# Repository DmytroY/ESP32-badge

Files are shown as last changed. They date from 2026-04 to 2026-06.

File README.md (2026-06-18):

# Electronic Conference Badge (ESP32)
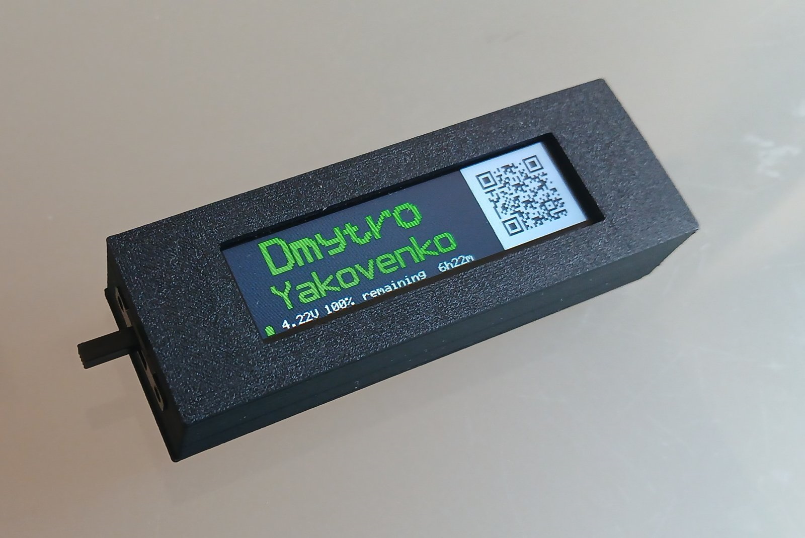
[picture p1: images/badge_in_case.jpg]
bage front view


A low-power embedded system featuring a custom display driver, web-based asynchronous configuration portal.
Is a result of full-stack embedded development, from low-level SPI driver authorship to UI/UX and power profiling.

## 1.Technical Overview
The system utilizes an ESP32 Super Mini to drive a 76x284 ST7789 LCD. With integrated WiFi it hosts a local web server to customize text, colors, and QR codes. Then transit into a power-efficiency monitoring state to maximize battery life while maintaining the display.

### 1.1. Custom Driver Development (ST7789)
Existing libraries failed to support the non-standard 76x284 resolution and integrated backlight control efficiently. So I developed a dedicated driver (lib/ST7789_76x284/) supporting drawing primitives, text rendering, and QR code generation. As important feature for this project the driver has integrated LEDC-based PWM for fine-grained backlight brightness control, allowing users to balance visibility against power consumption. 

[Driver API documentation link.](https://github.com/DmytroY/ESP32-badge/tree/main/lib/ST7789_76x284)

### 1.2. High-Frequency Hardware Integration & EMI Mitigation
During prototyping, long trace lengths led to significant RF interference between the WiFi antenna and the SPI bus/PWM signals. So I optimized physical pinout which allows reduce betwing boards connection lengths to <5mm for critical high-speed lines (SCLK, MOSI) and move the antenna to the edge of the device. This effectively eliminated signal crosstalk and ensured stable work of SPI and WiFi.

**NB !** 
- SCLK: 7
- MOSI: 8
- CS: 20
- DC: 10
- RST: 9
- Backlight (BL): 21
- Battery ADC: 0

 this ESP32 to LCD pinout is recomended to keep connections as short as possible and WiFi antenna on the edge of the device which prevents EMI.

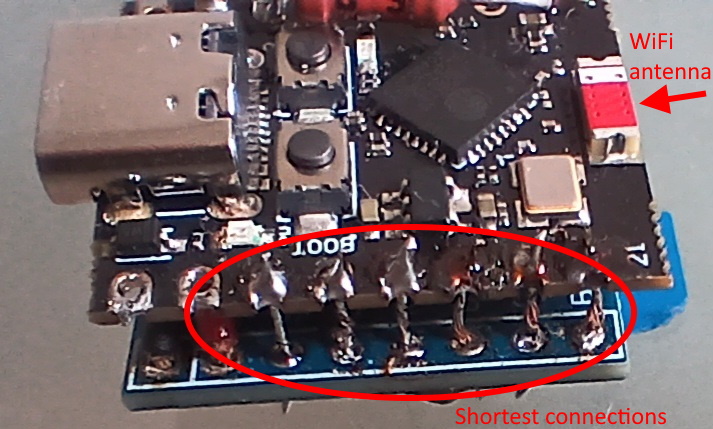
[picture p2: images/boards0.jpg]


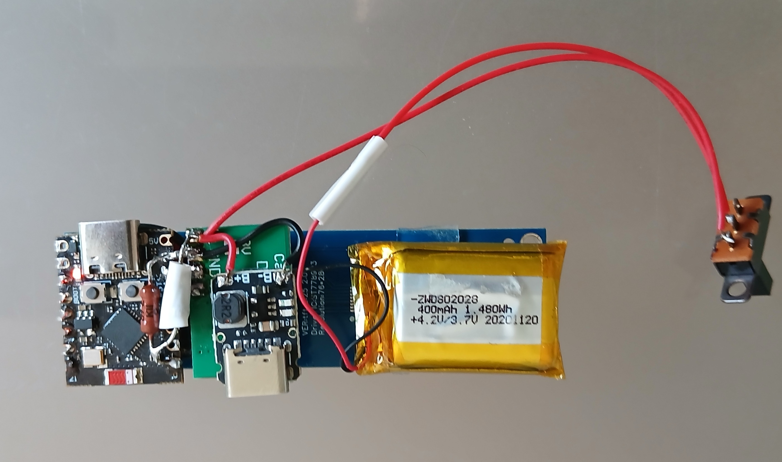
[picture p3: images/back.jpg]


### 1.3. Power Management & Battery Analytics
To achieve maximum operational uptime without losing the display state, the system employs next power strategy:

#### Optimized Light Sleep.
Since the display requires a PWM signal for the backlight, Deep Sleep was bypassed in favor of Light Sleep. This maintains the oscillator and pin registers while powering down the majority of the SoC.

#### Battery measurement Logic.
* ESP32-specific ADC non-linearity mitigated by implementing ADC characterization.
``` esp_adc_cal_characterize(ADC_UNIT_1, ADC_ATTEN_DB_11, ADC_WIDTH_BIT_12, 1100, &adc_chars); ```

* Digital Signal Processing using an Exponential Moving Average (EMA) filter to stabilize voltage readings:
``` bat_v = (bat_v_raw * 0.1f) + (bat_v * 0.9f);```

* to calculate remaining battery capacity accurately I use approximated voltage zones of non-linear voltage/capacity function of Li-Ion battery then provide real-time runtime estimates.

#### Consumption and lifetime
There are two modes of functioning.
* SETUP mode. System starts with running WiFi and server. After user input data and chose brightness sytem state transfers to
* DISPLAY mode. ESP32 shouts down server and WiFi, going to sleep mode. Only PWM for display backlight works and battery comsumption mostly depends on chosen screen brightness.

| Mode | Brightness| Current (mA)|
|------|-----------|-------------|
| Setup  | 50%     |     170     |
| Display| min     |     24      |
| Display| 50%     |     60      |
| Display| max     |     110     |

### 1.4. Software Architecture
The badge implements a "headless" configuration mode to keep the firmware footprint small and the UI responsive.

* Filesystem: HTML, CSS, and JS assets are decoupled from the binary and stored in Flash memory via **LittleFS**.

* Asynchronous Communication: The configuration portal uses **AJAX** (XMLHttpRequest) to submit user data (Title, Subtitle, Colors) without page refreshes, ensuring a seamless user experience.

### 1.5. Helper Utilities
The helper.cpp file provides procedures for
- File Serving: Logic for handling LittleFS file requests for the web server.
- Power Management: Routines for deep sleep and wake cycles.
 - Battery Diagnostics: Procedures for measuring ADC voltage and rendering battery status/remaining time indicators on the screen.

## 2. Hardware Configuration
The circuit is powered by a Li-ion battery, so it was necessary to address the issues of battery charging, charge level monitoring, and converting the Li-ion battery voltage to the 3.3 V supply voltage for the microcontroller and display. The following components were used:
- TP4056 - Li-ion battery charge controller with USB Type-C input 
- 350 or 400 mAh Li-ion battery
- DD0603SA DC/DC converter from 0.9-6V to 3.3V
- Power switch
- ESP32-C3_SuperMini development board with onboard WiFi
- 2.25-inch TFT LCD 76x284 resolution module with SPI interface and ST7789 controller 
- 7.5k / 6.2k divider connects the battery to PIN_0 (ADC) and shifts the voltage to the optimal ADC range.

<img src="images/badge_schematic.jpg" alt="bage schematic" width="500">

## 3. Software Installation notes
I have used PlatformIO IDE extension in VS Code. After cloning repository do not forget that Filesystem Image and main code should be uploaded separatelly:

- Upload to ESP32 filesystem: Open the PlatformIO sidebar, go to Project Tasks > Platform > Build Filesystem Image, click Upload Filesystem Image.

 - Upload Code: click the standard Upload arrow icon.

## 4. Usage
Watch Youtube video:

[![Watch the video](https://img.youtube.com/vi/PrKOngyS30c/2.jpg)](https://youtu.be/PrKOngyS30c)

- On power on the badge generates a unique SSID based on its MAC address.

<img src="images/badge_connect_WiFi.jpg" alt="WiFi connection screen" width="300">

- You can scan the QR code on the display or manually connect to the WiFi using password on screen.

- Visit 192.168.4.1 in your browser.

<img src="images/server0.jpg" alt="server initial page" width="300">

- Input Title (Name), Subtitle (Position or Surname), and string for generating QR Code (Link), choose colors and brightness.

<img src="images/server1.jpg" alt="server page with user input" width="300">

- Use the Test button to preview your design. Once satisfied, press Finish.

<img src="images/displ01.jpg" alt="display 3 fields" width="300">

<img src="images/displ02.jpg" alt="display 1 field" width="300">

**Remarks:** In case of Subtitle is not used Title field font and position will be automaticaly adjusten for beter visibility:

<img src="images/Title_only.jpg" alt="display 1 field" width="300">

- The badge will keep screen on, but enters sleep mode, waking briefly every 60 seconds to monitor battery and dispaly remaining time.

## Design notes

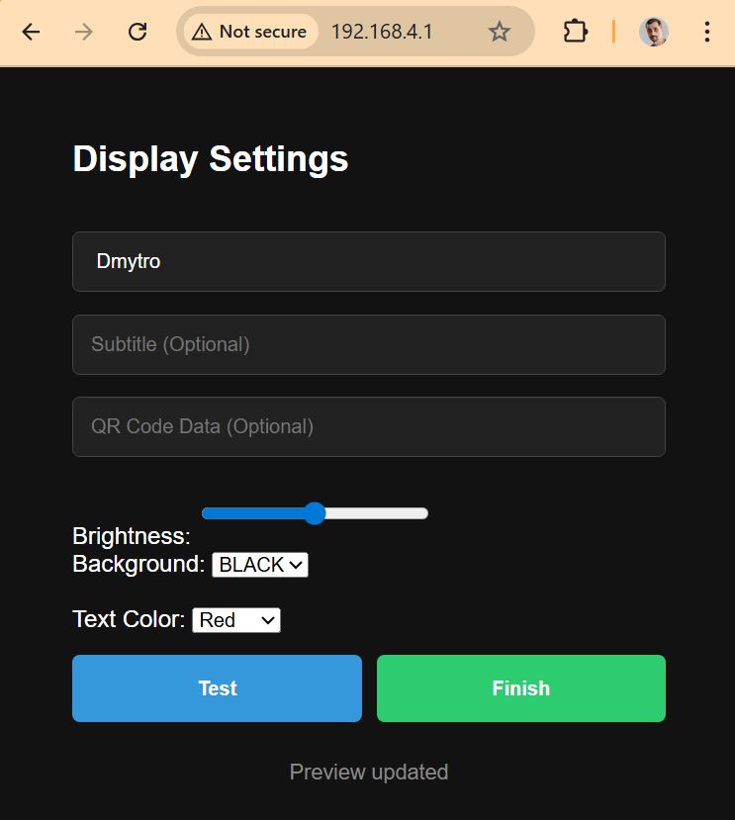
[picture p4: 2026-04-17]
images/server2.jpg

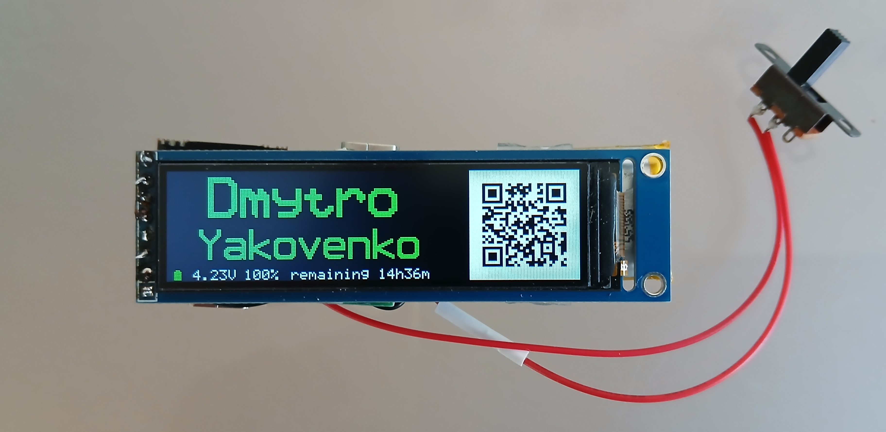
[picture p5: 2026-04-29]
images/displ02.jpg

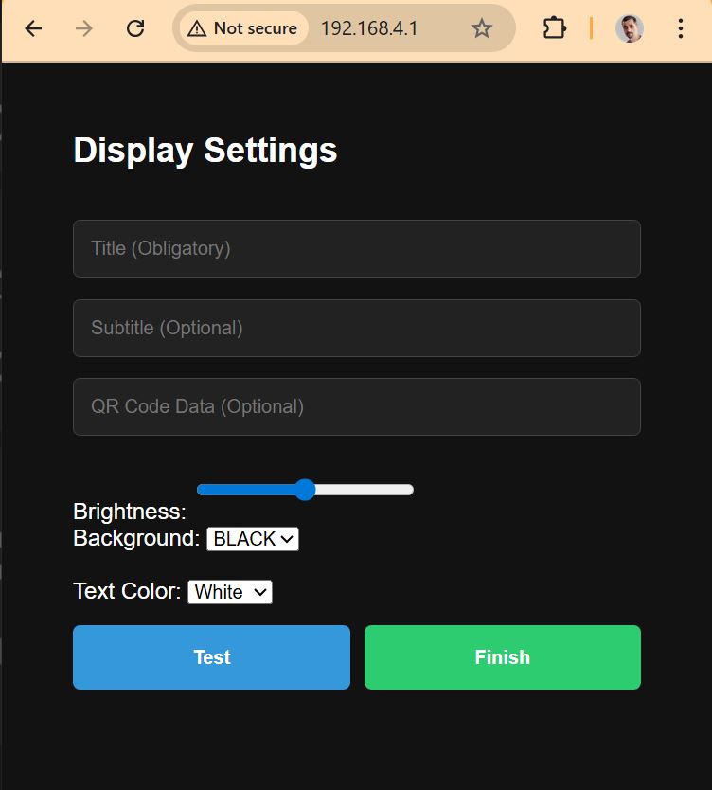
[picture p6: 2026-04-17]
images/server0.jpg

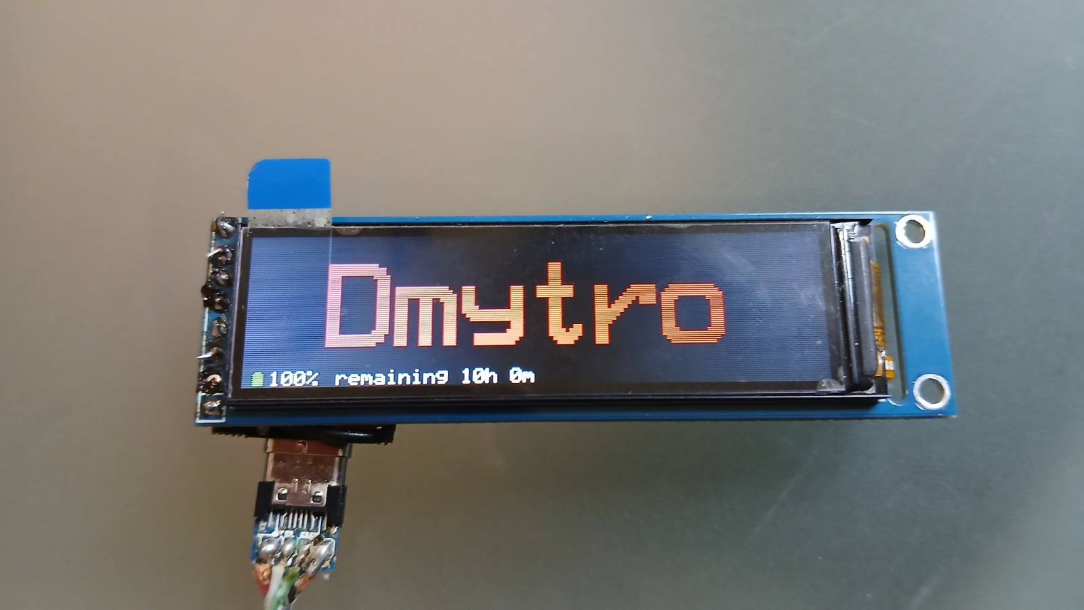
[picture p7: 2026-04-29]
images/Title_only.jpg

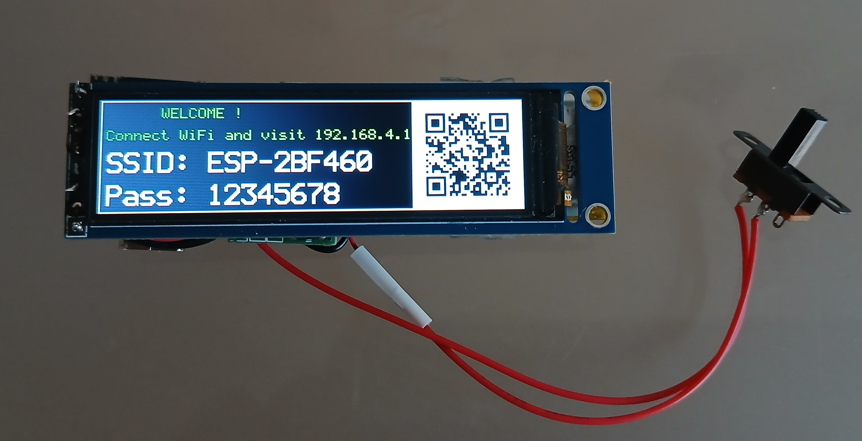
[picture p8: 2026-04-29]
images/displ00.jpg

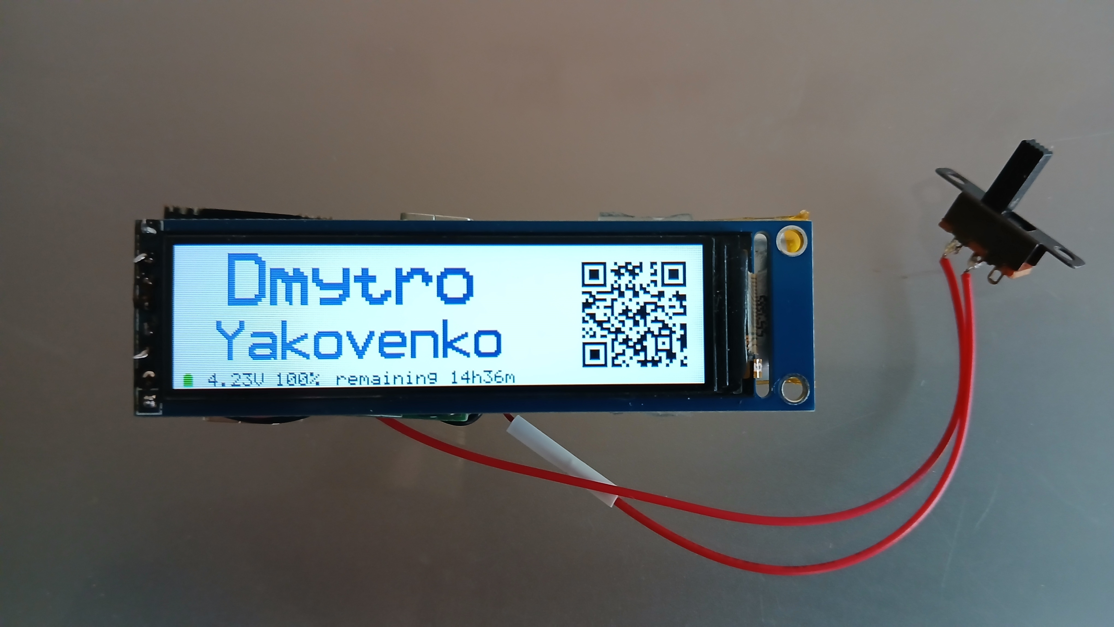
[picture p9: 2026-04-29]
images/displ01.jpg

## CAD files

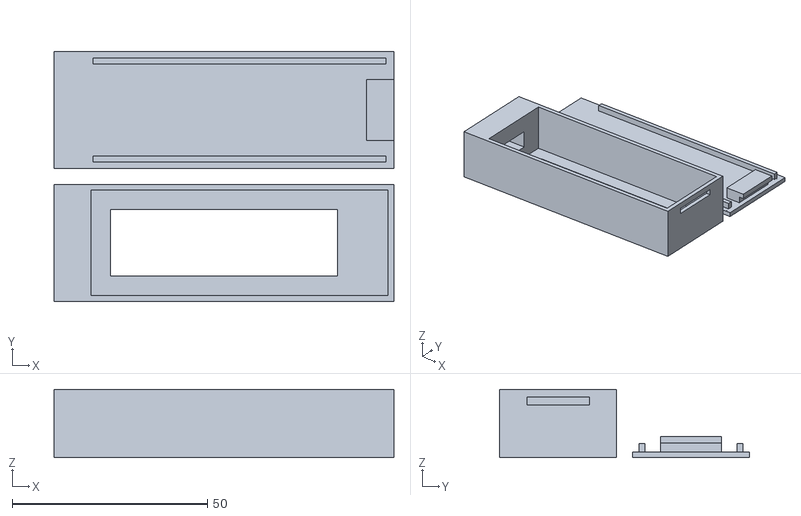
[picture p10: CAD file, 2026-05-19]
Badge case walls 1_5 mm.stl
87.0 x 64.0 x 17.5

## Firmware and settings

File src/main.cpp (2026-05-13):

#include <Arduino.h>
#include <WiFi.h>
#include "esp_wifi.h"
#include <ST7789_76x284.h>
#include "helper.h"


// --- WiFi settings ------
uint8_t mac[6];
char ssid[20]; // wil be determined based on WiFi MAC to be unique
#define PASS "12345678"

// ── Pin definitions ─────────────────────────────────────────────────
#define PIN_SCLK  7
#define PIN_MOSI  8
#define PIN_CS    20
#define PIN_DC    10
#define PIN_RST   9
#define PIN_BL    21
#define PIN_BAT   0

// ── Display geometry ────────────────────────────────────────────────
// landscape
#define TFT_W      284
#define TFT_H      76
#define X_OFFSET   18
#define Y_OFFSET   82

ST7789_76x284 tft(TFT_W, TFT_H, X_OFFSET, Y_OFFSET);
WebServer server(80);

unsigned brightness = 50;  // initial brightness 50%
const unsigned long TIMEOUT_MS = 300000; // 5 minutes timeout user activity 

String userTitle = "";
String userSubtitle = "";
String userQR = "";
String currentAction = "";;
bool newMessageReady = false;

uint16_t userTextColor = WHITE;
uint16_t userBgColor = BLACK;

// ── Setup ───────────────────────────────────────────────────────────
void setup() {

    esp_adc_cal_characterize(ADC_UNIT_1, ADC_ATTEN_DB_11, ADC_WIDTH_BIT_12, 1100, &adc_chars); // ADC calibration
    analogReadResolution(12);    // set resolution for ADC

    LittleFS.begin();

    WiFi.macAddress(mac);
    snprintf(ssid, sizeof(ssid), "ESP-%02X%02X%02X", mac[3], mac[4], mac[5]);
    WiFi.mode(WIFI_AP);
    WiFi.setTxPower(WIFI_POWER_2dBm); // decreased WiFi power
    WiFi.softAP(ssid, PASS, 1);

    serveFile(server, "/", "/index.html", "text/html");
    serveFile(server, "/style.css", "/style.css", "text/css");
    serveFile(server, "/script.js", "/script.js", "application/javascript");

    server.on("/msg", []() {
        userTitle = server.arg("title");
        userSubtitle = server.arg("subtitle");
        userQR = server.arg("qr");
        currentAction = server.arg("action"); // "test" or "finish"

        userTextColor = (uint16_t)strtol(server.arg("textColor").c_str(), NULL, 0);
        userBgColor = (uint16_t)strtol(server.arg("bgColor").c_str(), NULL, 0);
        brightness = server.arg("bright").toInt();

        // Safety Fallback: if colors match, force text to contrast
        if (userTextColor == userBgColor) {
            userTextColor = (userBgColor == 0x0000) ? 0xFFFF : 0x0000;
        }
        
        newMessageReady = true;
        server.send(200, "text/plain", "OK");
    });

    server.begin();

    tft.begin(PIN_SCLK, PIN_MOSI, PIN_CS, PIN_DC, PIN_RST, PIN_BL);
    tft.fillScreen(BLACK);
    // tft.drawRect(0, 0, TFT_W, TFT_H, WHITE);
    
    tft.drawText(5,   5, "Connect WiFi, visit 192.168.4.1", GREEN, BLACK, 1);

    // WIFi ON simbol
    tft.drawChar(0, 20, (char)0x86, WHITE, BLACK, 3);

    static char buf[32];
    snprintf(buf, sizeof(buf), "SSID:%s", ssid);
    tft.drawText(20,   20, buf, WHITE, BLACK, 2);
    snprintf(buf, sizeof(buf), "Pass:%s", PASS);
    tft.drawText(20,   43, buf, WHITE, BLACK, 2);

    // QR for WiFi connection
    static char qrBuffer[128];
    snprintf(qrBuffer, sizeof(qrBuffer), "WIFI:S:%s;T:WPA;P:%s;;", ssid, PASS);
    tft.drawQR(qrBuffer);

    indicateBatteryLevel(PIN_BAT, tft, brightness, userBgColor, false);

    tft.setBrightness(brightness);

    // ------ User data input -----
    unsigned long lastActivity = millis();
    while (currentAction != "finish")
    {
        server.handleClient();
        if (newMessageReady) {
            lastActivity = millis(); // Reset timer
            newMessageReady = false;
            tft.setBrightness(brightness);
            tft.fillScreen(userBgColor);

            // Render Preview
            if (userSubtitle.length() == 0){
                tft.drawText(UI::TITLE_X, UI::TITLE_1_Y, userTitle.c_str(), userTextColor, userBgColor, 6);
            } else {
                tft.drawText(UI::TITLE_X, UI::TITLE_2_Y, userTitle.c_str(), userTextColor, userBgColor, 4);
                tft.drawText(UI::TITLE_X, UI::SUBTITLE_Y, userSubtitle.c_str(), userTextColor, userBgColor, 3);
            }

            if (userQR.length() > 0) 
                tft.drawQR(userQR.c_str());
            
            indicateBatteryLevel(PIN_BAT, tft, brightness, userBgColor, false);
        }
        // Break by user inactivity timeout
        if (millis() - lastActivity > TIMEOUT_MS) {
            tft.setBrightness(50);
            tft.fillScreen(BLACK);
            // WIFi OF simbol
            tft.drawChar(0, 20, (char)0x85, WHITE, BLACK, 3);
            userBgColor = BLACK;
            tft.drawText(UI::TITLE_X + 25, UI::TITLE_2_Y, "Do not forget to", RED, userBgColor, 2);
            tft.drawText(UI::TITLE_X + 25, UI::TITLE_2_Y + 20, "connect charger.", RED, userBgColor, 2);
            tft.drawText(UI::TITLE_X + 25, UI::TITLE_2_Y + 40, "Reboot to restart server", WHITE, userBgColor, 1);
            break; 
        }
    }
    // ---- stop server ----
    server.stop();
    WiFi.softAPdisconnect(true);
    WiFi.disconnect(true);
    WiFi.mode(WIFI_OFF);
    esp_wifi_stop();
}

void loop() {
    indicateBatteryLevel(PIN_BAT, tft, brightness, userBgColor, true);
    goToSleep(60, PIN_BL);
}

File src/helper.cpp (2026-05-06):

#include "helper.h"

esp_adc_cal_characteristics_t adc_chars;  // Definition of ADC characteristics

void serveFile(WebServer &server, const char* route, const char* path, const char* mime) {
    server.on(route, [&server, path, mime]() {
        File file = LittleFS.open(path, "r");
        server.streamFile(file, mime);
        file.close();
    });
}

void goToSleep(unsigned sec, int8_t bl) {
    // send ESP32 in to light sleep and keep operational PWM on bl pin.
    // Usage: goToSleep(60, 10) where 60 is sleep time in secunds and 10 is pin connected to TFT backlight PWM.

    if(sec > 3600) sec = 3600; // max sleep not more than 1 hour

    // Keep RTC peripherals and 8M clock alive for PWM and GPIO holds
    esp_sleep_pd_config(ESP_PD_DOMAIN_RTC8M, ESP_PD_OPTION_ON);
    esp_sleep_pd_config(ESP_PD_DOMAIN_RTC_PERIPH, ESP_PD_OPTION_ON);

    // prevent GPIO PIN_BL isolation during sleep - required for backlight PW
    gpio_sleep_sel_dis((gpio_num_t)bl);

    // Configure Timer Wakeup (Time is in microseconds)
    uint64_t sleepTimeInUs = sec * 1000000ULL;
    esp_sleep_enable_timer_wakeup(sleepTimeInUs);

    // Start sleep
    esp_light_sleep_start();
    // waking up
    delay(100); // internal regulator and clocks to stabilize
}

float measureBattery(int8_t pin_bat){
    // returns volts.
    // Takes in to account ADC calibration and HW divider 
    uint32_t raw_v = analogRead(pin_bat); // read uncalibrated voltage
    uint32_t voltage_mv = esp_adc_cal_raw_to_voltage(raw_v, &adc_chars);  // Convert raw to mV using the calibrated characteristics
    return (voltage_mv * 2.16f) / 1000.0f; // Convert to actual battery voltage (7k5 + 6k2 voltage divider used)
}

int get_percentage(float v) {
    // appoximation of LiIon battery capacity based on voltage
    // lut is lookup table for lineary approximated zones
    if (v >= lut[0].voltage) return 100;
    if (v <= lut[lut_size - 1].voltage) return 0;

    for (int i = 0; i < lut_size - 1; i++) {
        if (v <= lut[i].voltage && v > lut[i+1].voltage) {
            // Linear interpolation between point i and i+1
            float diff_v = lut[i].voltage - lut[i+1].voltage;
            float diff_p = lut[i].percentage - lut[i+1].percentage;
            return lut[i+1].percentage + (int)((v - lut[i+1].voltage) * diff_p / diff_v);
        }
    }
    return 0;
}

void indicateBatteryLevel(int8_t pin_bat, ST7789_76x284 &tft, unsigned brightness, uint16_t bg_color, bool calculate_remaining_time_flag){
    // display batery icon, capacity % and estimated remaining time

    // be sure text is visible
    uint16_t text_color = (bg_color == BLACK) ? WHITE : BLACK;

    static float bat_v = measureBattery(pin_bat); // initial level
    float bat_v_raw = measureBattery(pin_bat); // curent level
    bat_v = (bat_v_raw * 0.3f) + (bat_v * 0.7f); //  EMA filter

    // Display battery voltage
    char bat_v_buff[6];
    snprintf(bat_v_buff, sizeof(bat_v_buff), "%.2fV", bat_v);
    tft.drawText(UI::BATTERY_VOLT_X, UI::BATTERY_INFO_Y, bat_v_buff, text_color, bg_color, 1);

    // Display battery %
    int bat_percent = get_percentage(bat_v);
    char bat_perc_buffer[5]; // 3-digit number + % + null terminator
    snprintf(bat_perc_buffer, sizeof(bat_perc_buffer), "%3d%%", bat_percent);
    tft.drawText(UI::BATTERY_PERCENT_X, UI::BATTERY_INFO_Y, bat_perc_buffer, text_color, bg_color, 1);

    // Display battery icon
    if(bat_percent <= 20)     { tft.drawChar(UI::BATTERY_ICON_X, UI::BATTERY_INFO_Y, (char)0x80, RED, bg_color, 1);}
    else if(bat_percent <= 40){ tft.drawChar(UI::BATTERY_ICON_X, UI::BATTERY_INFO_Y, (char)0x81, text_color, bg_color, 1);}
    else if(bat_percent <= 60){ tft.drawChar(UI::BATTERY_ICON_X, UI::BATTERY_INFO_Y, (char)0x82, text_color, bg_color, 1);}
    else if(bat_percent <= 80){ tft.drawChar(UI::BATTERY_ICON_X, UI::BATTERY_INFO_Y, (char)0x83, text_color, bg_color, 1);}
    else                      { tft.drawChar(UI::BATTERY_ICON_X, UI::BATTERY_INFO_Y, (char)0x84, GREEN, bg_color, 1);}

    // Display remaining time
    if(calculate_remaining_time_flag){

        // Polynomial approximation of draining current depending on display brightness (mA)
        float current = 0.00755 * brightness * brightness + 0.32 * brightness + 20;
        // defining remained time based on remaining charge and draining current
        float remained_hours = (bat_max_cap * bat_percent / 100.0f) / current;
        int rem_time_h = static_cast<int>(remained_hours); // remaining time in hours
        int rem_time_m = static_cast<int>((remained_hours - rem_time_h) * 60);

        // static const unsigned start_time = millis();
        // static const float start_bat_v = measureBattery(pin_bat);
        // static const int start_bat_percent = get_percentage(start_bat_v);

        // unsigned long elapsed = millis() - start_time;
        // float discharge_speed = (elapsed > 60000) ? (start_bat_percent - bat_percent) / (elapsed / 3600000.0f) : 10;
        // discharge_speed = (discharge_speed  > 0) ? discharge_speed : 2.33;

        // div_t remaining = div(bat_percent, discharge_speed);

        // int rem_time_h = remaining.quot; // remaining time in hours
        // int rem_time_m = static_cast<int>(60.0f * remaining.rem/discharge_speed); // remaining time in minutes
        
        char rem_time_buffer[17]; // including null terminator
        snprintf(rem_time_buffer, sizeof(rem_time_buffer), "remaining %2dh%2dm", rem_time_h, rem_time_m);
        tft.drawText(UI::BATTERY_INFO_X, UI::BATTERY_INFO_Y, rem_time_buffer, text_color, bg_color, 1);

    } else {
        tft.drawText(UI::BATTERY_INFO_X, UI::BATTERY_INFO_Y, "remaining ..h..m", text_color, bg_color, 1);
    }

}

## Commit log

2026-04-29 Fix image filename case in README
    Corrected image filename case for consistency.
2026-06-18 battery spesification
    Updated battery specifications in the hardware configuration section.
2026-06-18 battery capacity in README
    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
